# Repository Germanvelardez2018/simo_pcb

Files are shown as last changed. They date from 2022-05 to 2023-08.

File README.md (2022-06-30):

# Simo pcb

## Proyecto en construccion.

<h2>
    Diseño y construccion de PCB de conexion para el dispositivo drifter modular SIMO (Sistema de Monitoreo).
</h2>

## Diseñador: German Velardez

### Breve resumen del proyecto a realizar:

El proyecto consiste en el diseño y prueba de concepto de un dispositivo tipo drifter basado en una placa de desarrollo y modulos tipo arduino.
Para realizar la conexion de los distintos elementos se diseñara dos placas PCB:
*  **Simo Shield** (dentro de carpeta simo_shield)
*  **Simo Bateria** (dentro de carpeta sdimo_bateria)

## Simo Shield
 PCB para interconectar los siguientes elementos:
  * **Placa de desarrollo basada en STM33F103xx** (Bluepill)
      <div align="center" >
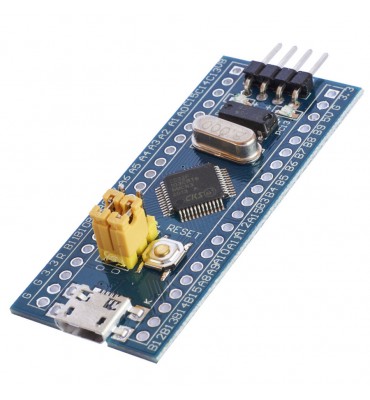
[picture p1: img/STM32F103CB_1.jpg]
     
     </div>

  *  **Modulo comunicacion 4G  diseñado por Elemon** (EESA-IOT SIM7000G PLACA SHIELD 2G/CAT-M1/NB1/GNSS)
      <div align="center" >
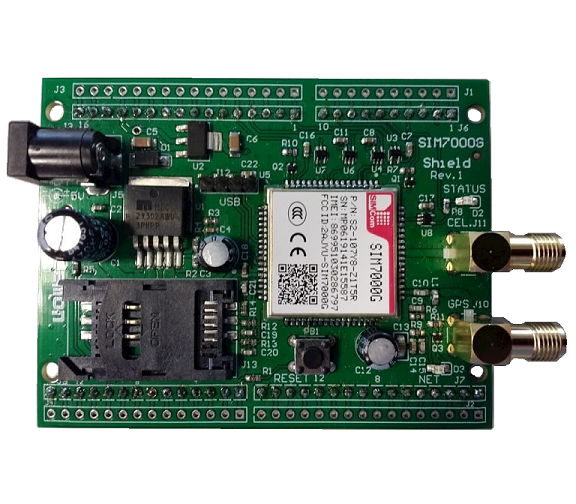
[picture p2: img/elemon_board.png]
       
       </div>
  *  **Sensor acelerometro** (MPU6050)
     <div align="center" >
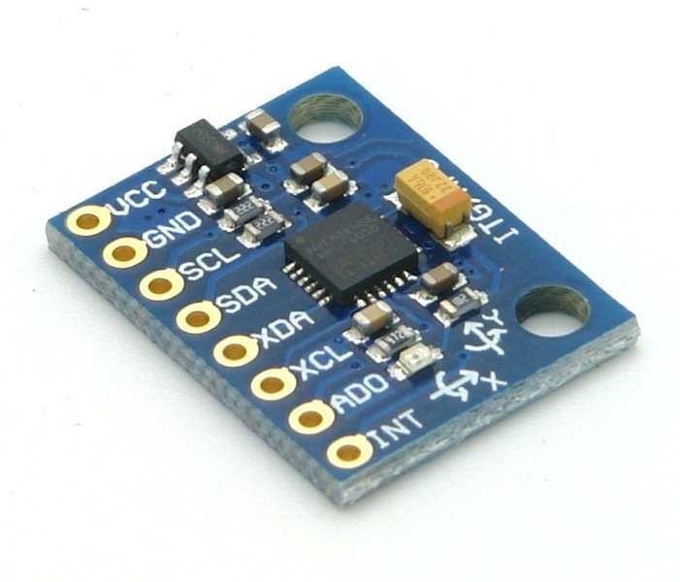
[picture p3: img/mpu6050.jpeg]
       
       </div>
  *  **Memoria flash externa para almacenar datos** (AT45DB)
     <div align="center" >
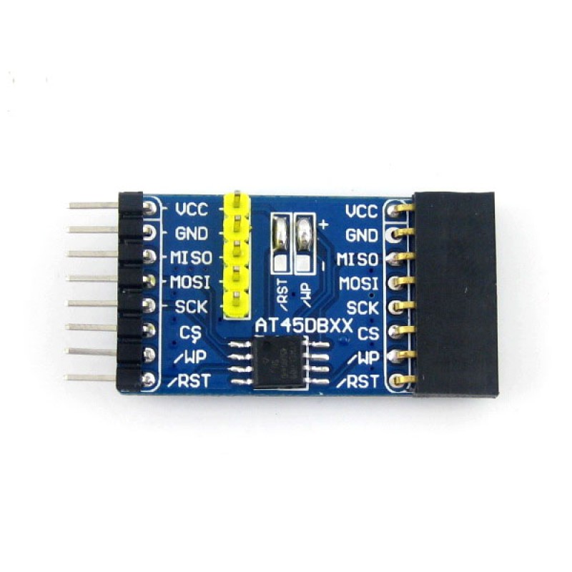
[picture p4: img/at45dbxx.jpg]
       
       </div>
  *  **Conector para acceso a puerto UART de debug**
     <div align="center" >
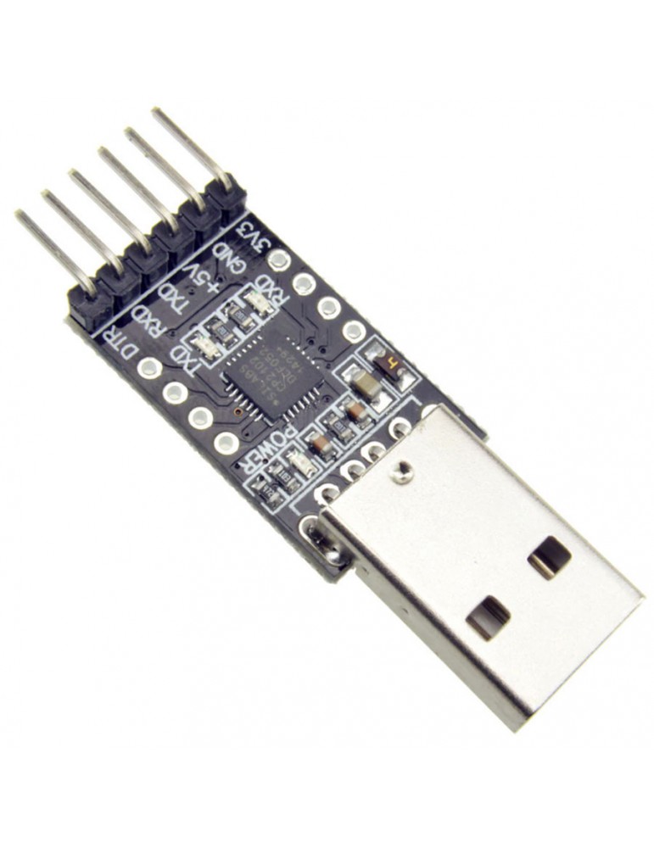
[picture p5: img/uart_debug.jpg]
       
       </div>

## Simo Bateria
 Este PBC tiene como objetivo gestionar los elementos necesarios para que el dispositivo pueda funcionar con Baterias.
 PBC para interconectar los siguientes elementos:
 * **2 porta baterias 18650**
 * **Regulador Step Down (LM2596S)**
 * **Conectores de salida varios**

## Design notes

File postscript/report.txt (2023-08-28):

Trazado a '/home/germanv/Documentos/repos/simo-pcb/simo_shield/Gerber/simo_shield_1-B_Cu.ps'.
Trazado a '/home/germanv/Documentos/repos/simo-pcb/simo_shield/Gerber/simo_shield_1-Edge_Cuts.ps'.
Trazado a '/home/germanv/Documentos/repos/simo-pcb/simo_shield/Gerber/simo_shield_1-Margin.ps'.
Info: Listo.

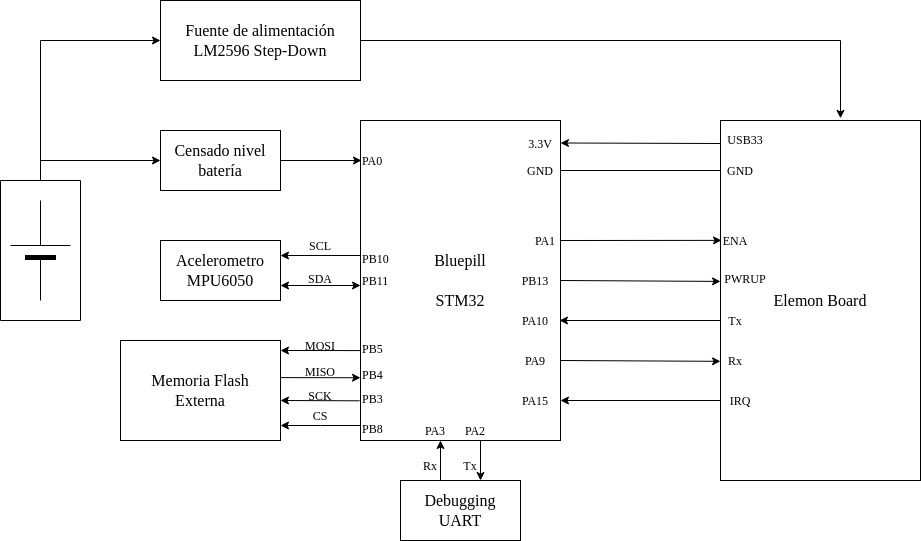
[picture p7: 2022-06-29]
img/Drifter.jpg

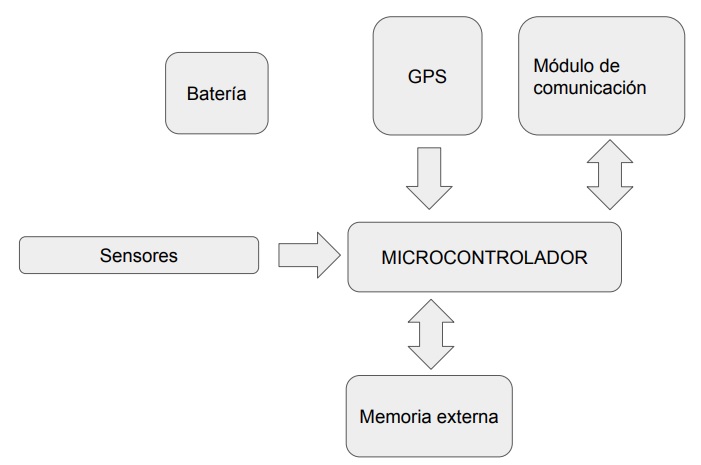
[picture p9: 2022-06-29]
img/diagrama_sistema.jpg

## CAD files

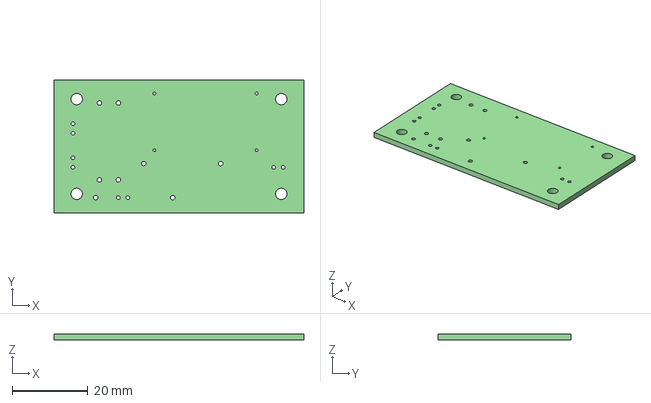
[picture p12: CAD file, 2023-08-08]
respaldo/simo_bateria/simo_bateria.step
66.0 x 35.0 x 1.60 mm

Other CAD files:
simo_bateria.step

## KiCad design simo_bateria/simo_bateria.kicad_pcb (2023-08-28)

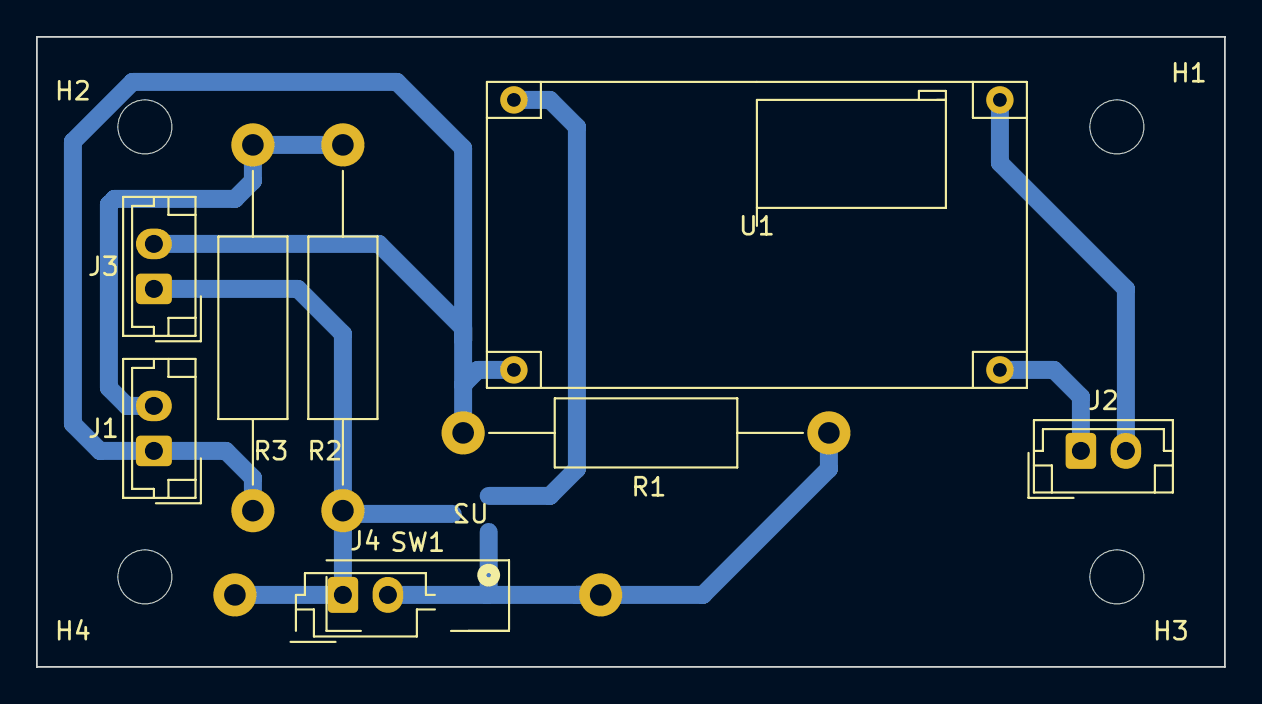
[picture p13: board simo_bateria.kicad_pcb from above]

Board: 2 copper layers, 66.0 x 35.0 mm, 14 parts (1 on the bottom side), 7 nets.

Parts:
H1, H2, H3, H4: MountingHole; MountingHole_3mm
J1: BAT_LEVEL; JST_EH_B2B-EH-A_1x02_P2.50mm_Vertical
J2: Plugin; JST_EH_B2B-EH-A_1x02_P2.50mm_Vertical
J3: VBAT IN; JST_EH_B2B-EH-A_1x02_P2.50mm_Vertical
J4: SWD; JST_EH_B2B-EH-A_1x02_P2.50mm_Vertical
R1: 10k; RESITOR_THT
R2: 355k; RESITOR_THT
R3: 155k; RESITOR_THT
SW1: SW_Reed; RESITOR_THT
U1: mod_mt3608; mt3608_v2
U2: BSS314PEH6327XTSA1; TRANS_BSS314PEH6327XTSA1_INF

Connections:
GND: J1.1, J3.2, R1.2, R3.2, U1.2 (VIN-)
unnamed: J1.2, R2.1, R3.1
unnamed: J2.1, U1.4 (VOUT-)
unnamed: J2.2, U1.3 (VOUT+)
unnamed: J3.1, J4.1, R2.2, SW1.1, U2.3
unnamed: J4.2, R1.1, SW1.2, U2.1
unnamed: U1.1 (VIN+), U2.2

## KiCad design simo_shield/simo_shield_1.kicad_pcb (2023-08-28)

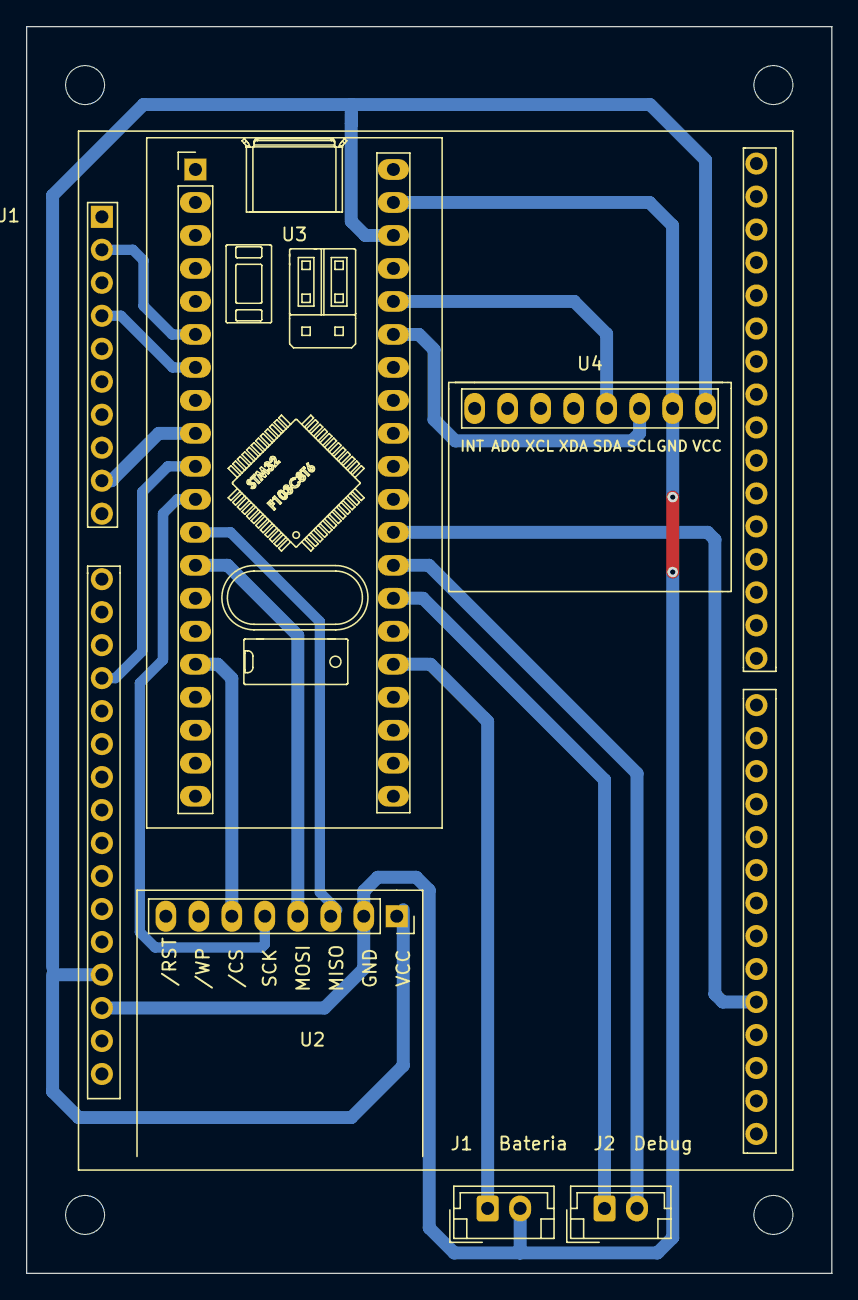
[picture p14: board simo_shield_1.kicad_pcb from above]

Board: 2 copper layers, 62.0 x 96.0 mm, 10 parts (0 on the bottom side), 16 nets.

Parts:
H1, H2, H3, H4: MountingHole; MountingHole_3mm
J1, J2: Conn_01x02_Female; JST_EH_B2B-EH-A_1x02_P2.50mm_Vertical
U1: elemon_board; elemon_board_compacto
U2: modulo_flash_externa; conector_flash_ext
U3: bluepill_board_stm32; YAAJ_BluePill_SWD_1_modificado
U4: modulo_acelerometro; MPU6050

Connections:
+3.3V: U1.23 (USB33), U2.1 (VCC), U3.38 (3V3), U4.8 (VCC)
/BAT_ENA_PIN: U1.52 (BAT_ENA), U3.29 (PA4)
/UART_DEBUG_RX: J2.1, U3.27 (PA2)
/UART_DEBUG_TX: J2.2, U3.28 (PA3)
GND: J1.2, U1.24 (GND), U2.2 (GND), U3.39 (GND), U4.7 (GND)
unnamed: J1.1, U3.25 (PA0)
unnamed: U1.4 (SER3_TX), U3.7 (PA10)
unnamed: U1.9 (PWRKEY), U3.9 (PA12)
unnamed: U1.14 (RI), U3.10 (PA15)
unnamed: U2.3 (MISO), U3.12 (PB4)
unnamed: U2.4 (MOSI), U3.13 (PB5)
unnamed: U2.5 (SCK), U3.11 (PB3)
unnamed: U2.6 (/CS), U3.16 (PB8)
unnamed: U1.2 (SER3_RX), U3.6 (PA9)
unnamed: U3.35 (PB10), U4.6 (SCL)
unnamed: U3.36 (PB11), U4.5 (SDA)

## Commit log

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2022-05-16 se agrego carpeta bluepill donde se agrupo archivos relacionados con la placa de desarrollo bluepill
    [simo_pcb.kicad_sch]
2022-05-16 modificaciones en elemon_board symbol
    [simo_pcb.kicad_sch]
2022-05-17 organizando proyectos en carpetas: 2 proyectos , simo_shield (principal) y simo_bateria
    [simo_bateria.kicad_pcb, simo_bateria.kicad_sch, simo_shield.kicad_sch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]
2022-05-17 se completaron todos los modelos 3d y se verifico las footprint
    [MPU_6050.iges, MPU_6050.step, MPU_6050.stl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]
2022-05-17 se hizo mas compacta pcb shield
    [simo_bateria.kicad_pcb, simo_bateria.kicad_sch, simo_shield_1.kicad_pcb]
2022-05-19 se agrego conector de bateria a ambas placas
    [JST-B2B-EH-A.STEP, JST-S2B-EH-A.STEP, simo_bateria.kicad_pcb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]
2022-05-19 se guardaron modelos 3d de ambas placas en formato step
    [Pin Header Male 01x01 P2.54mm.stp, Pin Header Male 01x02 P2.54mm.stp, Pin Header Male 01x03 P2.54mm.stp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]
2022-05-19 update, se corrijio imagen step de simo_bateria
    [simo_bateria.kicad_pcb]
2022-05-31 se diseñaron las pistas de placa shield simo, revisar
    [simo_shield_1.csv, simo_shield_1.kicad_pcb, simo_shield_1.kicad_sch]
2022-06-01 verifique conexiones en simo shield, todo ok.
    [simo_shield_1.kicad_pcb, simo_shield_1.kicad_sch]
2022-06-02 en esquematico pin 35 y 36 se conectan con SDA y SCL de MPU6050. En PCB no aparece tal conexion
    [simo_shield_1.kicad_pcb, simo_shield_1.kicad_sch]
2022-06-02 casi terminado, revisar PCB, error de conexion pero no entiendo por que.
    [STM32F103C8T6_Blue_Pill v6.step, pec11r-4215k_l13-8_w12-4_h21-5.stp, simo_shield_1.kicad_pcb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]
2022-06-06 update en pcb shield
    [simo_shield_1.kicad_pcb, simo_shield_1.kicad_sch]
2022-06-06 simo shield pcb listo para revision
    [simo_shield_1.kicad_pcb]
2022-06-06 se actualizo la placa bateria
    [simo_bateria.kicad_pcb, simo_bateria.kicad_sch]
2022-06-08 se agrego un circuito para mediciones de tension de bateria mediante la bluepill
    [simo_bateria.kicad_pcb, simo_bateria.kicad_sch, simo_shield_1.kicad_pcb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]
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2022-06-28 esquemas listos para revisar
    [simo_bateria.kicad_pcb, simo_bateria.kicad_sch, simo_shield_1.kicad_sch]
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2022-06-29 update placa simo bateria
    [simo_bateria.kicad_sch]
2022-06-30 Se hizo refactory del proyecto simo_bateria
    [simo_bateria.kicad_sch, simo_shield_1.kicad_sch]
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2022-07-04 update en ambas placas. Cambio de formato de carpetas. Footprint asignado pero modelos 3d aun no.
    [Pin Header Male 01x01 P2.54mm.stp, Pin Header Male 01x02 P2.54mm.stp, Pin Header Male 01x03 P2.54mm.stp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]
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2022-07-05 update en ambas placas, revision 02
    [simo_bateria.kicad_pcb, simo_bateria.kicad_sch, simo_shield_1.kicad_pcb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]
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2022-07-06 update 2. Listo para revision 2
    [simo_bateria.kicad_pcb, simo_bateria.kicad_sch, simo_shield_1.kicad_pcb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]
2022-07-06 modificaciones menores en placa simo bateria. La salida del divisor de tension estaba mal ubicada.
    [simo_bateria.kicad_sch]
2022-07-06 modificaciones en simo_shield: modulo_flash_externo
    [simo_shield_1.kicad_sch]
2022-07-07 update pcb:simo_bateria. Listo para segunda revision
    [simo_bateria.kicad_sch]
2022-07-07 comenzamos el diseño del PCB de shield simo.
    [simo_shield_1.kicad_pcb, simo_shield_1.kicad_sch]
2022-07-11 simo shield: primer prototipo de pista terminado. 0 errores 26 warning. Todos por cortes en serigrafia
    [simo_shield_1.kicad_pcb, simo_shield_1.kicad_sch]
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2022-07-18 actualizacion en placa simo shield: correccion de inconsistencias en el modulo bluepill clone
    [simo_shield_1.kicad_pcb, simo_shield_1.kicad_sch]
2022-07-18 actualizacion de placa simo shield: se mejoro el ruteo y se agreggo plano de 3v3
    [simo_shield_1.kicad_pcb]
2022-07-18 simo shield: se actualizo el numero de revision y fecha
    [simo_shield_1.kicad_pcb, simo_shield_1.kicad_sch]
2022-07-19 modificaciones en simo shield:Se modificaron los planos para enderezar los planos y se pulio detalles
    [simo_shield_1.kicad_pcb]
2022-07-19 modificaciones simo shield: esquema y PCB. Detalle: se modifico la alimentacion y eliminaron conectores custom
    [simo_shield_1.kicad_pcb, simo_shield_1.kicad_sch]
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2022-07-20 Placa simo bateria: Se modificaron conectores custom en esquema
    [simo_bateria.kicad_pcb, simo_bateria.kicad_sch]
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2022-08-04 Corregidos detalles en plano de Vcc y eliminada pista de GND en pin 39 del Bluepill.
    [simo_shield_1.kicad_pcb]
2022-08-04 update: placa bateria, correccion de error en esquematico:GND de la salida LEVEL
    [simo_bateria.kicad_pcb, simo_bateria.kicad_sch]
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2022-09-07 update: PINB13 paso a ser PA12. Modificar en firmware
    [simo_shield_1.kicad_pcb, simo_shield_1.kicad_sch]
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2022-10-03 update: pines de uart sim7000g conectados correctamente, mejor posicionamiento de memoria flash externa. PCB mas compacto
    [simo_shield_1.kicad_pcb]
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2022-10-04 modificaciones en pcb: se reposiciono sensor mpu6050,borneras y el pin de reset por software
    [simo_shield_1.kicad_pcb]
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2023-05-04 revision 3.0. Esquema. PCB con posicionamiento tentativo. Falta ver la posicion definitiva y mas conveniente del switch magnetico
    [simo_bateria.kicad_pcb, simo_bateria.kicad_sch]
2023-05-08 se agrego bornera para el switch magnetico. El pcb tengo 2 warnings a revisar
    [simo_bateria.kicad_pcb, simo_bateria.kicad_sch]
2023-05-31 Se efectuaron los siguientes cambios: - Corrección pista frente a conector J3. - Modificación de pista entre SW y R1.
    [simo_bateria.kicad_pcb]
2023-08-08 [Modificaciones] Reduccion de PCB para fabricar con CNC
    [simo_bateria.kicad_pcb, simo_bateria.step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]
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2023-08-28 [simo_bateria] Se elimino plano de tierra, faltaban archivos por actualizar
    [simo_bateria.kicad_pcb, simo_bateria.kicad_sch, simo_bateria.step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]
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

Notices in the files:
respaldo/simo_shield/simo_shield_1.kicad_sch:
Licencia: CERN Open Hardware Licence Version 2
